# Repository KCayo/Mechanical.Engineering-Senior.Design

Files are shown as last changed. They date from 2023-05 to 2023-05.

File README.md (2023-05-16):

# Mechanical.Engineering-Senior.Design
Developed the design of an innovative articulating ankle to optimize the performance of a lower extremity SCUBA diving prosthetic, employing the Solidworks/Cad program for design, utilizing the UConn machine shop for fabrication, and employing Python and the Digital Image Correlation Engine (DICe) program for comprehensive analysis.

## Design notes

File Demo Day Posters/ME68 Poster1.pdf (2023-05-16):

v | | ME Team 68 Design of an Articulating Ankle
| MECHANICAL ENGINEERING | | Sponsor: University of Hartford of Rehabilitation Sciences

## for Enhanced Performance

Advisor: Dr. Jason Lee | Rachael Crow, Eric Brodeur, Kevin Cayo

Introduction/Motivation

Design/Methodology

Test Rig Setup

Design 1: Tension Spring & Elastic Band

Results & Analysis Design 1

Objective: Design and develop a functioning articulating prosthetic ankle that can be utilized both on land and in subsurface environments for rehabilitation purposes Scope: Research, design, fabricate, and test an articulating ankle that allows for effective and comfortable use both on land and for SCUBA Diving without adjustment to ankle position when switching

environments
Parties of Interest:
- Transtibial amputees
- Ex Military & Veterans

Metrics:
- Ankle range of motion
- Recovery & Down stroke

Critical Design Features: ● Obtaining “ideal” ankle range of motion ○ 65 degrees from the vertical ● Limit Energy Exertion ● Weather and water resistant

- Goal: Create a device that allows for a balanced stroke while not locked in a fixed position
- Prosthetic ankle produces similar stroke as able ankle - focus on recovery & down stroke
- Inspirational Research
- Rampro “Swimankle”
- Nakashima Design
- Human Anatomy
- Design Components:
- Spring Constant Range: .1 - 1.5 N/mm ■ 0.1 N/mm, 0.5 N/mm & 1.3 N/mm
- Elastic Band Length: 50.8 mm
■ 1, 5, 10
- Pin: 10.5 mm diameter
- Initial Concerns:
- Longevity
■ Solution - Decrease pin diameter

Attractions:
- Previous research has
been conducted
- Variation of design
has been used
- Allows for variation in
type of component
used
- Spring or band

Motor Set Up:
- 1800 rpm motor
- Gear box of 40:1 ratio
- Allowed for 45 kicks per minute
- Motor stand to fit over the tank
- 80/20 stand
- Arm configuration
- 2 aluminum pieces - 508 mm
- 1 wooden piece - 1219.2 mm
- 1 aluminum piece - 482.6 mm ■ Key cut out for motor
attachment
■ Hole location for wooden arm connection

Tank Construction:
- 80/20 frame was used for frame
- Plexi glass was used for the sides and bottom of tank
- Water leakage prevention
- Gasket & Caulk
- Flex tape & Spray
- Wooden supports
- Reduce bowing of
plexiglass due to
pressure of water

Rampro “Swimankle”

Initial Drawing | CAD Model

Drawing with Motor Set Up

Initial CAD Model

Initial
Drawing

Motor & Gearbox

Final Design - Rubber Band

Final Design

Final Design - Tension Spring

VS.

- Strongest recovery stroke
- Narrowest peak
- Weakest downstroke
- Lacks full ankle
extension
- Good downstroke
- Near full extension of
foot
- Good recovery stroke
- Narrow peak
- Most balanced design of
three tension springs
- Weakest recovery
- Thickest peak
- Strong downstroke
- Full ankle extension

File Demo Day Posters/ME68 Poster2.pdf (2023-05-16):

v | | ME Team 68 Design of an Articulating Ankle
| MECHANICAL ENGINEERING | | Sponsor: University of Hartford of Rehabilitation Sciences

Design 2: Torsional Spring

Results & Analysis Design 2

Design 3: Ball & Joint

Design Comparison & Final Design

Conclusions & Recommendations

## for Enhanced Performance

Advisor: Dr. Jason Lee | Rachael Crow, Eric Brodeur, Kevin Cayo
- Design Components:
- Max Torque Range: 250 - 650 N*mm
■ 258.74, 268.93, 383.02, 508.43, 623.45
- Pin: 10.5 mm diameter
- Initial Concerns:
- Overextension
■ Solution - Add pin to limit range of motion

Attractions:
- Most sleek &
compact design
- Generates a lot of
torque to help with
recovery stroke
- Design Components:
- Lubricant: Oil or putty based
- Elastic Band: 50.8 mm
- Initial Concerns:
- Lubrication Dissipation
■ Solution - Use of putty lubricant

Attractions:
- Most human like
- Larger range of
motion

UConn: Jason Lee, Vito Moreno, Thomas Mealy Sponsor: Duffy Felmlee & Stephen Charry

1. “Activankle & Swimankle, Prosthetic Ankle Joints for Swimming, Jet/Snow Skiing, Rowing.” Rampro, https://www.rampro.net/ .
2. “Journal of Biomechanical Science and Engineering.” Development of the Transfemoral Prosthesis for Swimming Focused on Ankle Joint Motion, vol. 8, no. 1, 2013, p. 93. Journal of Biomechanical Science and Engineering, https://www.jstage.jst.go.jp/article/jbse/8/1/8_79/_pdf.

Acknowledgements

References

Initial Drawing

Initial CAD Model

Initial CAD Model

Initial Drawing

- Conclusions
- Torsion spring 3 performed best with ankle range of motion
- Tension spring 2 produced the most balanced stroke out of design 1 & torsional spring 3 produced the most balanced stroke out of design 2
■ Torsional spring 3 performed better in terms of downstroke ■ Tension spring 2 performed better in terms of recovery stroke
- Flipper deflection was inconclusive
■ Require a larger tank with slower arm oscillation
- Can create a design that doesn’t require position adjustments
- Recommendations
- Complete Human Testing
■ Focus on quantitative & qualitative metrics
- Flipper Deflection & ankle range of motion
- SWOLF, pace, heart rate, & comfortability
- Pursue finding “ideal” spring constant for tension spring design
- Fabricate and test Ball & Joint Design

Final Design

- Strongest recovery
- Narrowest peak
- Weakest downstroke
- Ankle not fully extended
- Satisfactory recovery
- Slightly thicker peak
- Good downstroke
- Almost full extension of ankle
- Less powerful recovery
- Thicker peak
- Strong Downstroke
- Full extension of ankle
- Weaker recovery
- Thicker peak
- Stronger Downstroke
- Full extension of ankle
- Weakest recovery
- Thickest peak
- Strongest Downstroke
- Full extension of ankle
- Closest path to ankle
range of motion
- Tension spring iteration 2 and torsion spring iteration 3 had the best balance of their respective springs
- Torsion design had a stronger downstroke with a fully extended ankle while tension design had a better recovery
- Able ankle has longer
downstroke and shorter
upstroke because of
required energy and drag
- Could not simulate because powerful motor generated
constant oscillation & no
flipper use in test rig testing
- Torsional spring design has a more similar downstroke while tension spring design has a more similar upstroke
- Both have same recovery angle as able foot

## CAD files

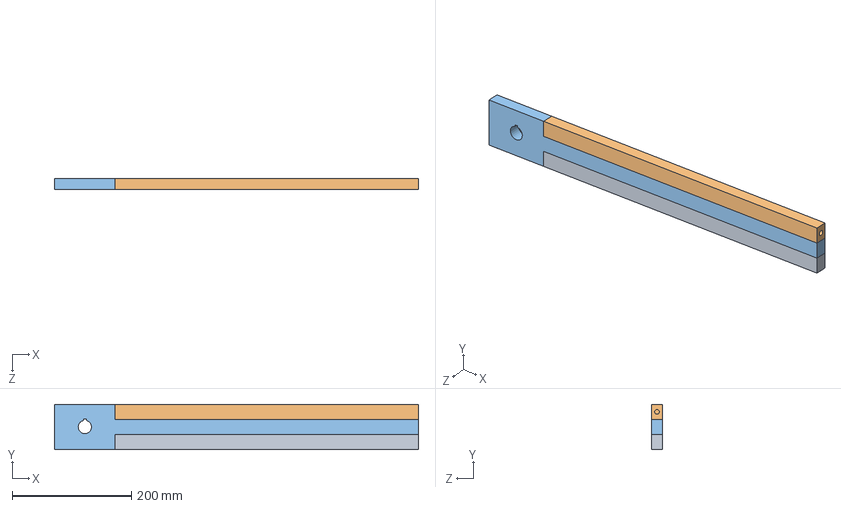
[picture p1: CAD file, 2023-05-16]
CAD Files/Arm Files/Arm Assembly.SLDASM
609.6 x 76.2 x 19.1 mm
Connector Arm
Ankle Arm
Gearbox Arm

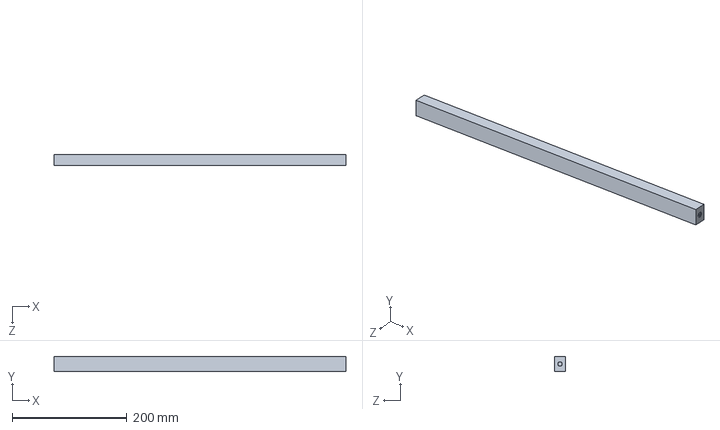
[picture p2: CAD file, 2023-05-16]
CAD Files/Arm Files/Ankle Arm.SLDPRT
508.0 x 25.4 x 19.1 mm

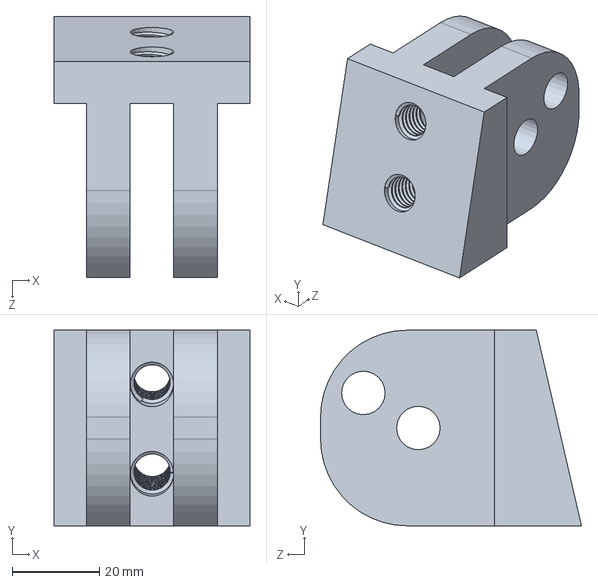
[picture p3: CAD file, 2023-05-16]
CAD Files/Simple CAD Model/Testing Bottom (Tension Spring).SLDPRT
45.0 x 45.0 x 60.0 mm

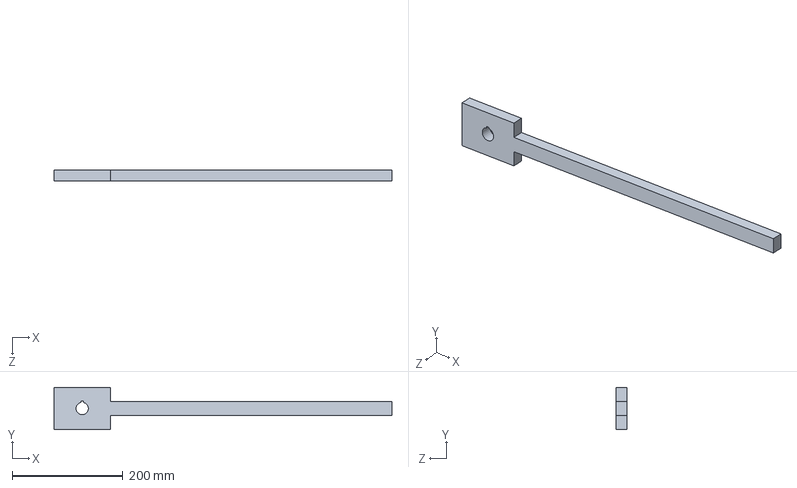
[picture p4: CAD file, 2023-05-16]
CAD Files/Arm Files/Gearbox Arm.SLDPRT
609.6 x 76.2 x 19.1 mm

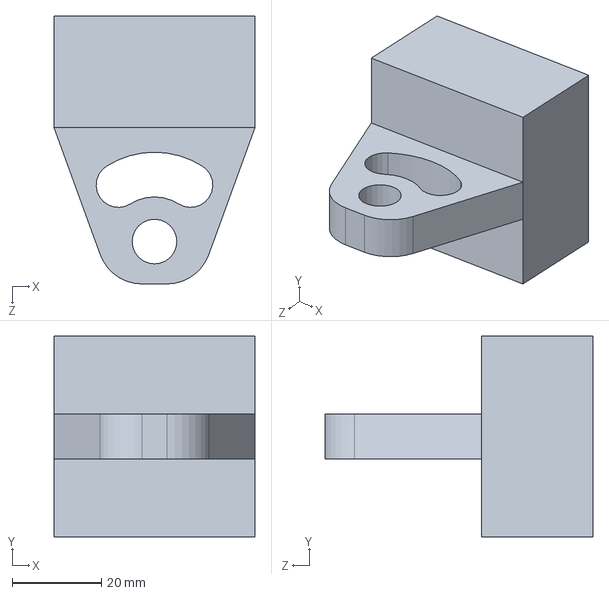
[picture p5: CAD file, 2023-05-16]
CAD Files/Simple CAD Model/Testing Top (Tension Spring).SLDPRT
45.0 x 45.0 x 60.0 mm

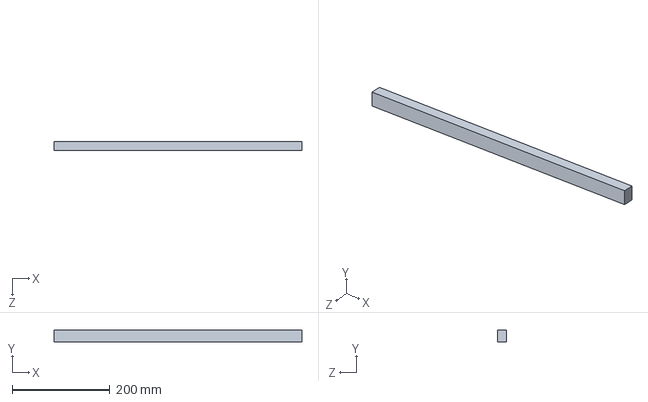
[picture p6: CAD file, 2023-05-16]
CAD Files/Arm Files/Connector Arm.SLDPRT
508.0 x 25.4 x 19.1 mm

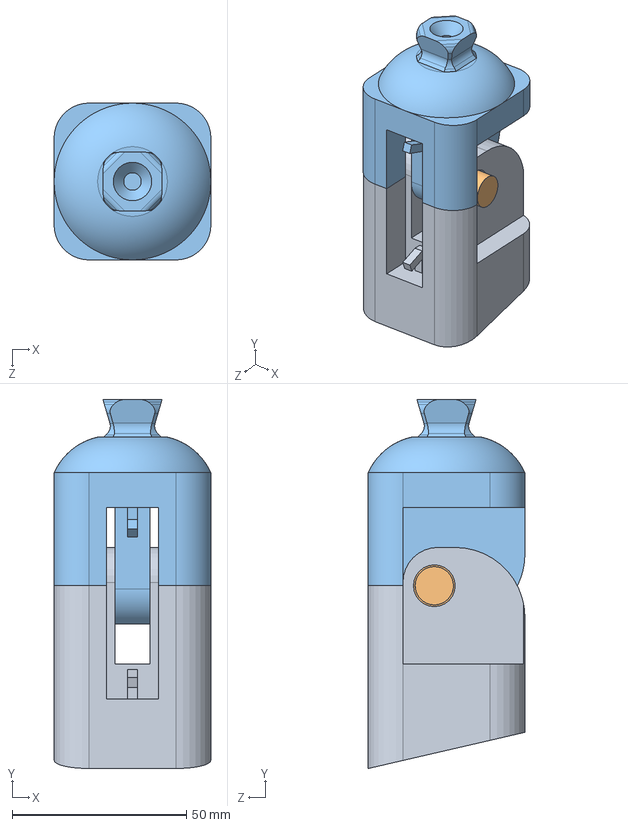
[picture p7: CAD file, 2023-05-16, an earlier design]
CAD Files/Old CAD Files/Linear Spring 3D Files/Linear Spring Assembly.SLDASM
45.0 x 106.0 x 45.0 mm
Linear Spring Bottom Half
Linear Spring Pin
Linear Spring Top Half

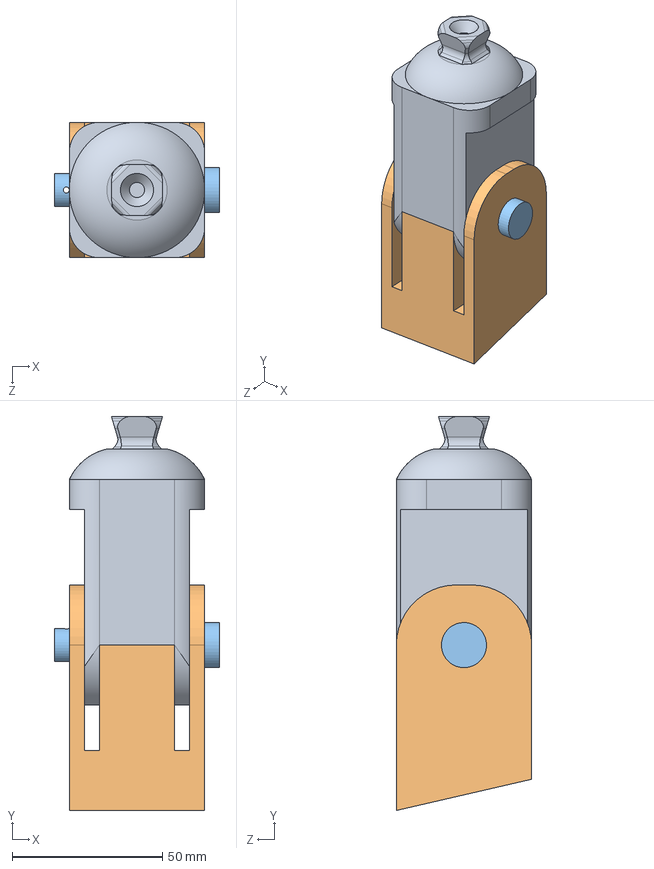
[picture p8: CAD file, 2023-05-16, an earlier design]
CAD Files/Old CAD Files/Torsional Spring 3D Files/Torsional Spring Assembly.SLDASM
55.0 x 131.0 x 45.0 mm
Torsional Spring Top Half
Torsional Spring Bottom Half
Torsional Spring Pin

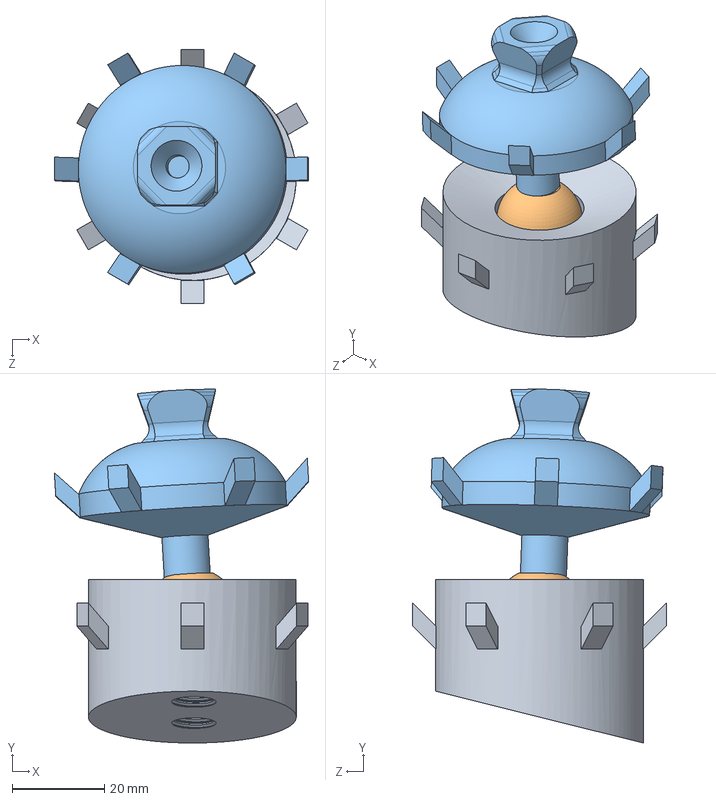
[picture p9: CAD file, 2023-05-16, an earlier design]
CAD Files/Old CAD Files/Ball-Joint 3D Files/BJL Assembly.SLDASM
55.1 x 76.6 x 54.9 mm
Bottom
Ball
Joint

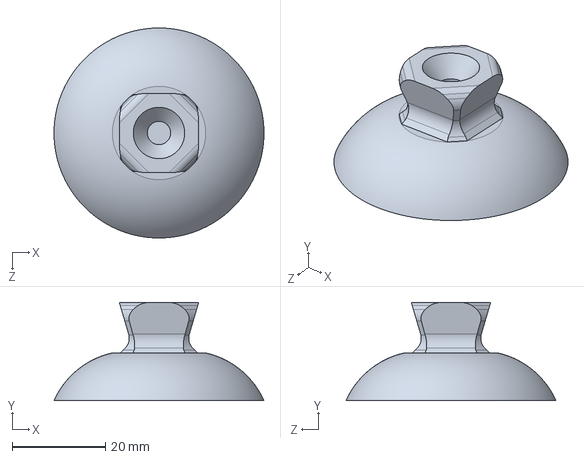
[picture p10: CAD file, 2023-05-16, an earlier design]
CAD Files/Old CAD Files/ARN-025G-DWG-0110-113.SLDPRT
45.0 x 21.0 x 45.0 mm

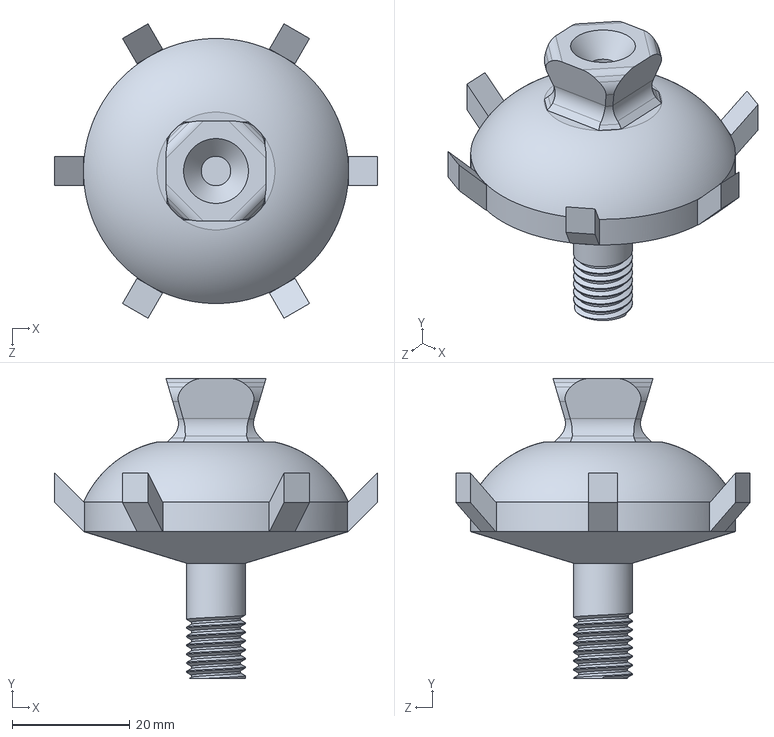
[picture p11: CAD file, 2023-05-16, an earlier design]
CAD Files/Old CAD Files/Ball-Joint 3D Files/Joint.SLDPRT
54.9 x 51.0 x 50.0 mm

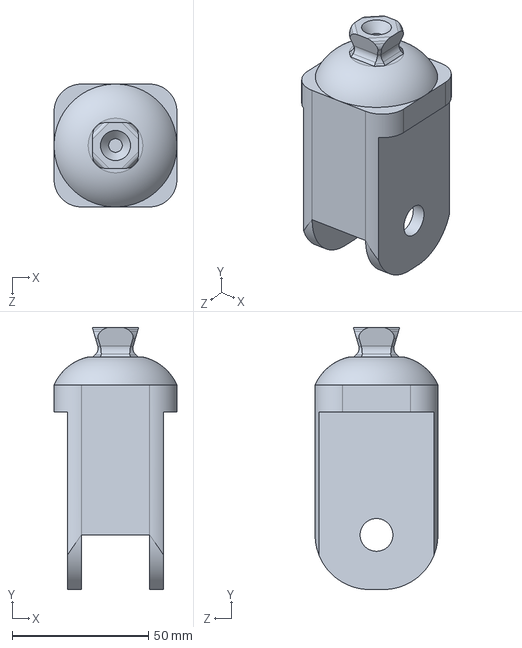
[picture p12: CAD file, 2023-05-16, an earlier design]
CAD Files/Old CAD Files/Torsional Spring 3D Files/Torsional Spring Top Half.SLDPRT
45.0 x 96.0 x 45.0 mm

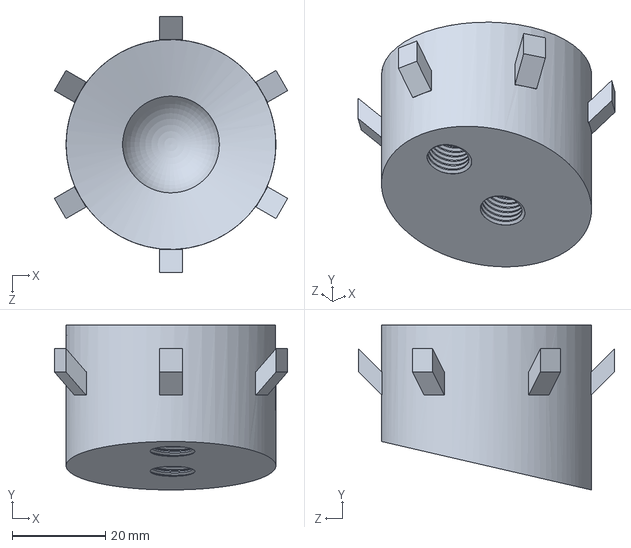
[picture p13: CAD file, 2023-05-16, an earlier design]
CAD Files/Old CAD Files/Ball-Joint 3D Files/Bottom.SLDPRT
50.0 x 35.4 x 54.9 mm

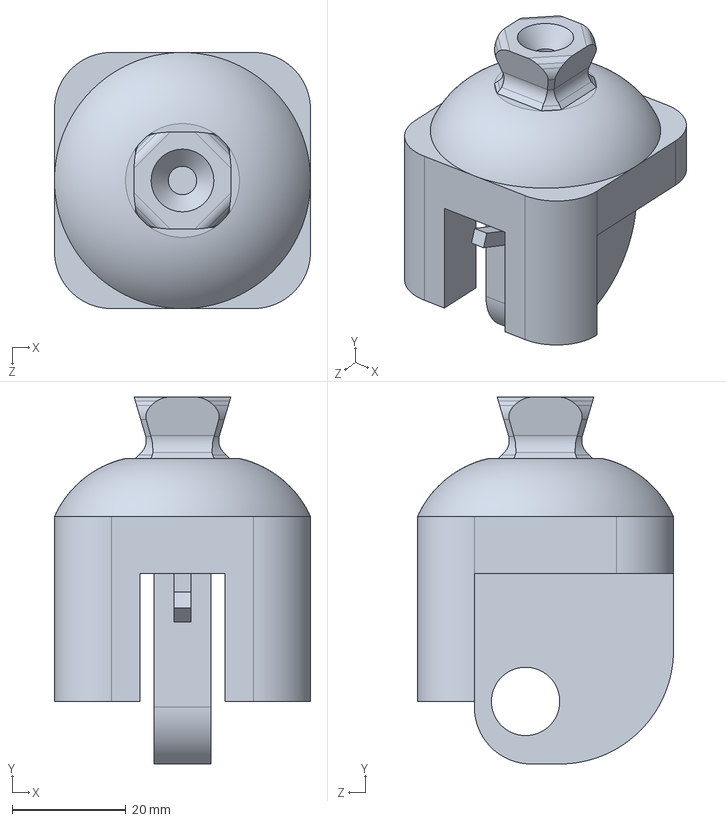
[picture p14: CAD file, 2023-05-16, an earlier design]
CAD Files/Old CAD Files/Linear Spring 3D Files/Linear Spring Top Half.SLDPRT
45.0 x 64.5 x 45.0 mm

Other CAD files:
CAD Files/Old CAD Files/Ball-Joint 3D Files/Ball.SLDPRT
CAD Files/Old CAD Files/Linear Spring 3D Files/Linear Spring Bottom Half.SLDPRT
CAD Files/Old CAD Files/Torsional Spring 3D Files/Torsional Spring Bottom Half.SLDPRT
CAD Files/Old CAD Files/Linear Spring 3D Files/Linear Spring Pin.SLDPRT
CAD Files/Arm Files/Ankle Arm.SLDDRW
CAD Files/Arm Files/Connector Arm.SLDDRW
CAD Files/Arm Files/Gearbox Arm.SLDDRW
CAD Files/Old CAD Files/Ball-Joint 2D Files/Ball.SLDDRW
CAD Files/Old CAD Files/Ball-Joint 2D Files/Bottom.SLDDRW
CAD Files/Old CAD Files/Ball-Joint 2D Files/Joint.SLDDRW
CAD Files/Old CAD Files/Linear Spring 2D Files/Linear Spring Bottom Half.SLDDRW
CAD Files/Old CAD Files/Linear Spring 2D Files/Linear Spring Pin.SLDDRW
CAD Files/Old CAD Files/Linear Spring 2D Files/Linear Spring Top Half (2).SLDDRW
CAD Files/Old CAD Files/Linear Spring 2D Files/Linear Spring Top Half.SLDDRW
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

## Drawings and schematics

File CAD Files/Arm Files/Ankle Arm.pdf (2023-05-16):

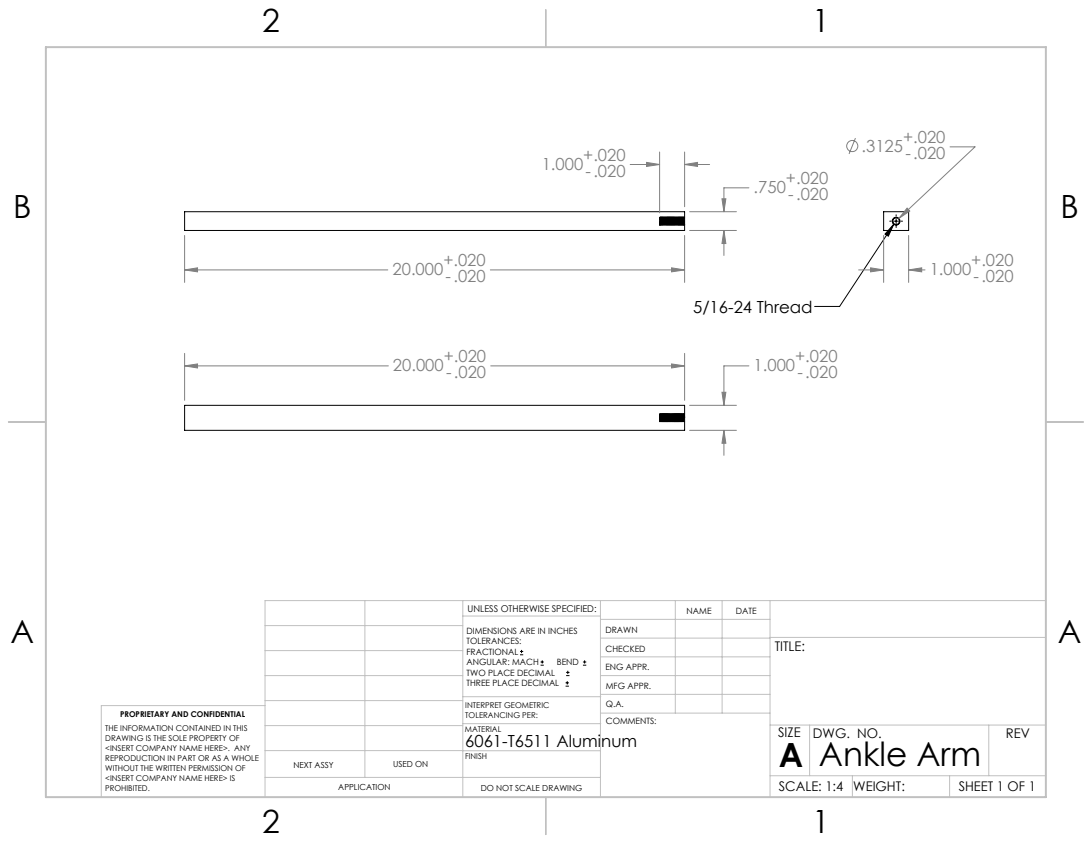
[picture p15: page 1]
5/16-24 Thread

UNLESS OTHERWISE SPECIFIED: | | NAME | DATE
DIMENSIONS ARE IN INCHES TOLERANCES: FRACTIONAL ANGULAR: MACH BEND TWO PLACE DECIMAL THREE PLACE DECIMAL | DRAWN

CHECKED | | | TITLE:

ENG APPR.
MFG APPR.

INTERPRET GEOMETRIC TOLERANCING PER: | Q.A.
MATERIAL 6061-T6511 Aluminum | | SIZE A | DWG. NO. Ankle Arm | REV

PROPRIETARY AND CONFIDENTIAL
THE INFORMATION CONTAINED IN THIS
DRAWING IS THE SOLE PROPERTY OF
<INSERT COMPANY NAME HERE>. ANY
REPRODUCTION IN PART OR AS A WHOLE
WITHOUT THE WRITTEN PERMISSION OF
<INSERT COMPANY NAME HERE> IS
PROHIBITED.

NEXT ASSY | USED ON | FINISH

APPLICATION | DO NOT SCALE DRAWING | | SCALE: 1:4 | WEIGHT: | SHEET 1 OF 1
